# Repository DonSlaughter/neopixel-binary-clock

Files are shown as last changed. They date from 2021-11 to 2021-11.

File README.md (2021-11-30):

# neopixel-binary-clock
Binary clock using Neopixels, ESP8266 and DS3231 real time clock.
I used PlatformIO for this Project. The Arduino IDE will do fine i guess.

# Known Problems
The first LED has some kind of Voltage spikes if WiFi is enabled. The trick is
to Compile this Code that the RTC gets a Timestamp and then Compile this Code
without WiFi. If someone can help with that it would be great, but it works
without WiFi.

# PCB Design
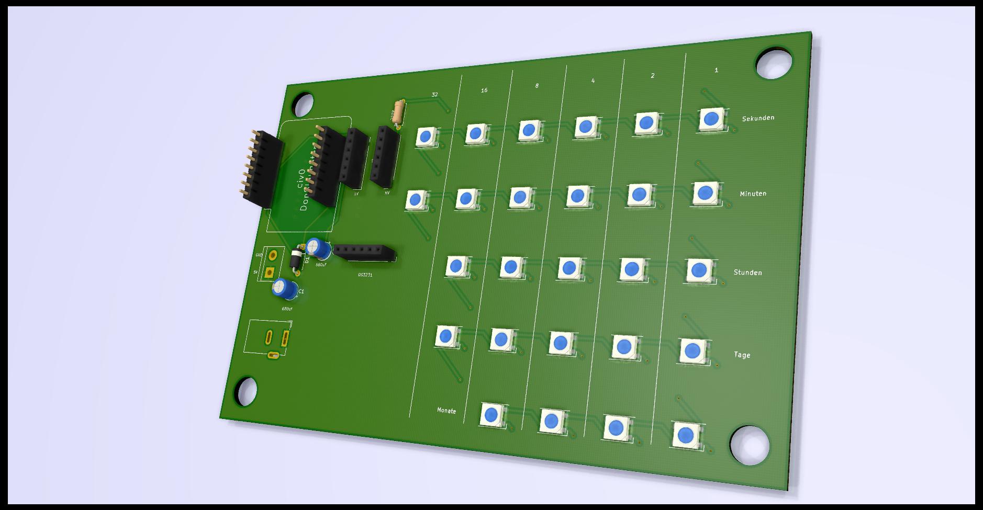
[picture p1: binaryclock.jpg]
pcb


# idea from civ0
https://github.com/civ0/neopixel-binary-clock

## Timezones
Timeszones are changend with Lib 'Timezones.h'
Everything can be changed with TimeChangeRule.

## Parts
* ESP8266 WeemosD1 Mini
* Logic Level Shifter
* DS3231
* 220 Ohm Resistor
* Schottky Diode with low Voltage drop
* 2 x Capacitor 680uF
* Barrel Jack
* Screw Terminal
* 26 x WS2812B SMD Led's

## Connect to Wi-Fi
create a file named secrets.h in the folder src.
it should contain your wifi network (ssid) and your wifi password:
```c
const char *ssid = "";
const char *pass = "";
```
## Code
Code needs to be cleand up

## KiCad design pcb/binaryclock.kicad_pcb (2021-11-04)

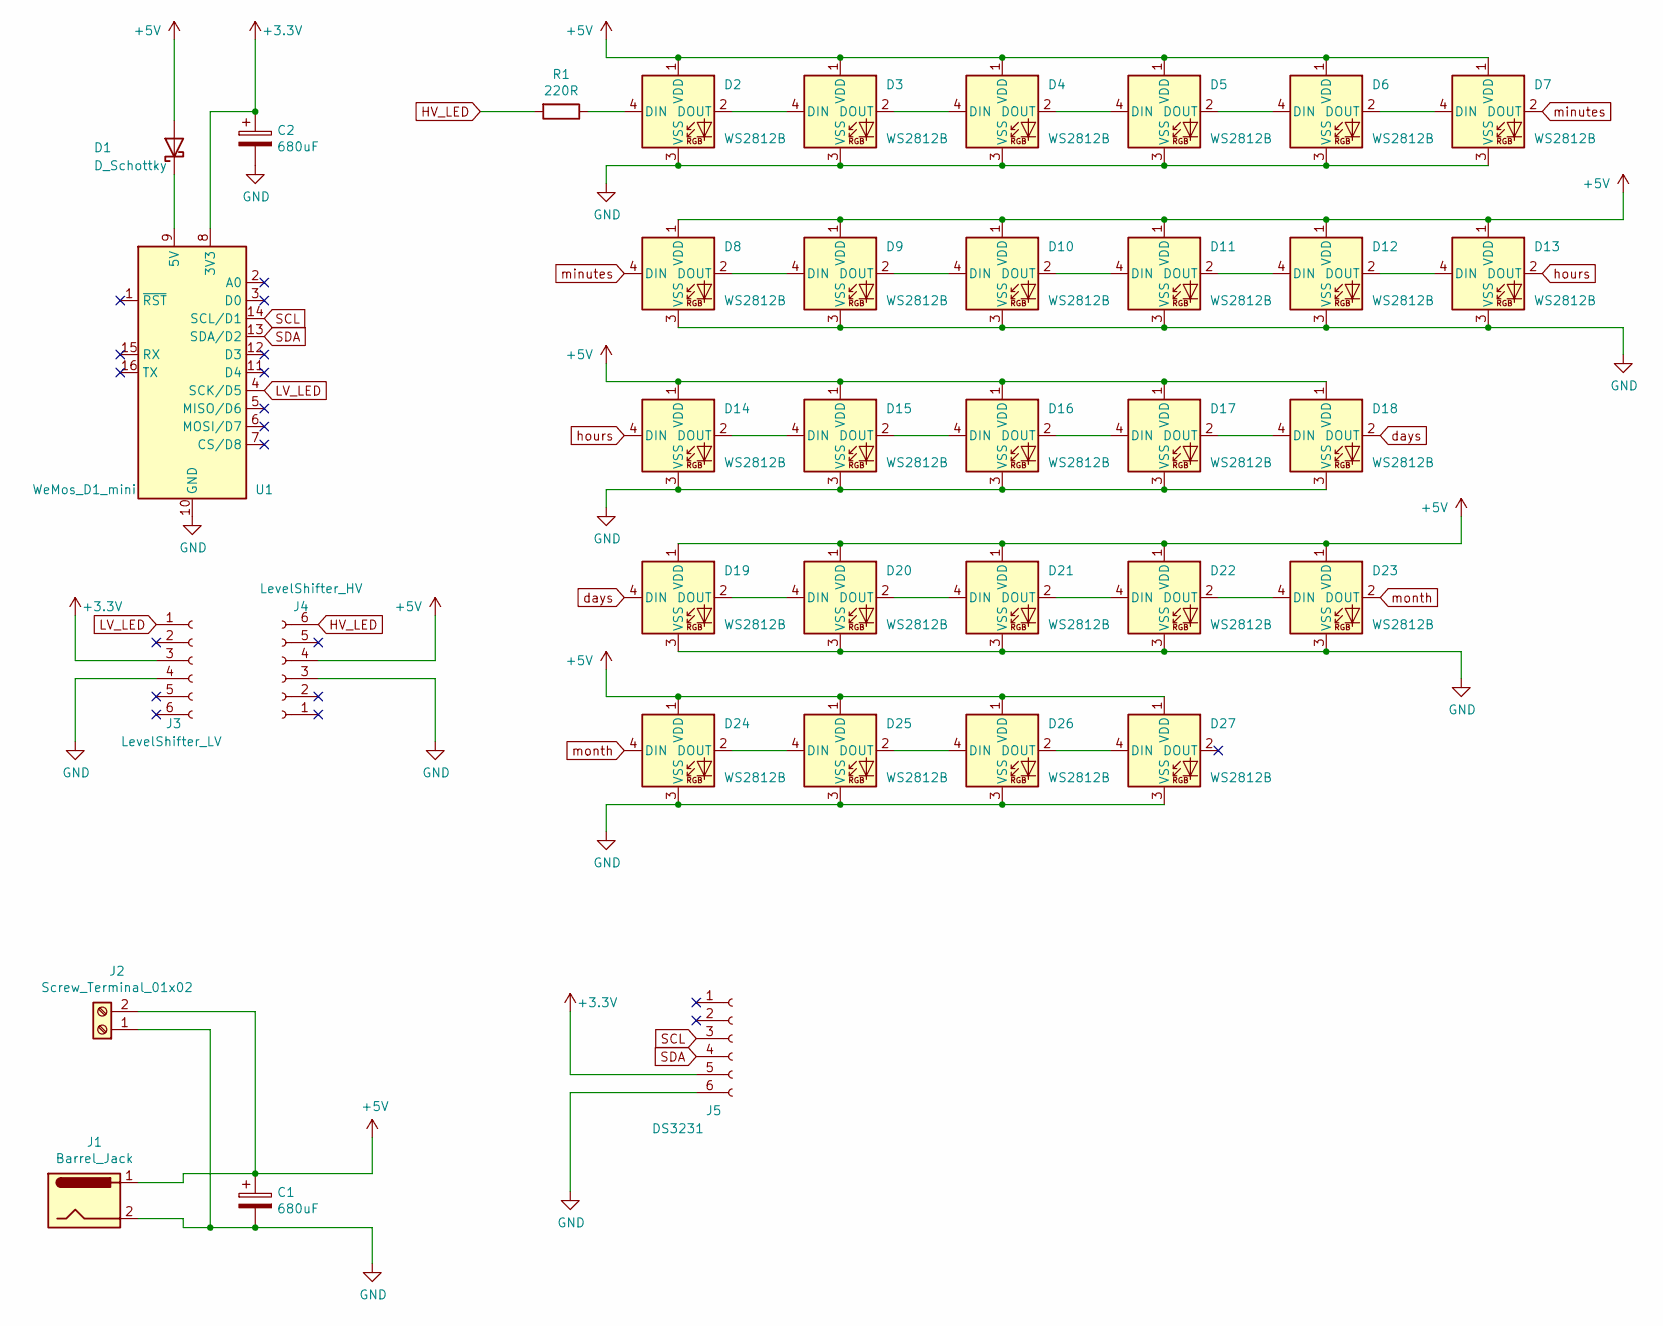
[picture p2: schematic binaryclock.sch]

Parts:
C1, C2: 680uF; CP_Radial_D5.0mm_P2.50mm
D1: D_Schottky; D_A-405_P7.62mm_Horizontal
D2, D3, D4, D5, D6, D7, D8, D9, D10, D11, D12, D13, D14, D15, D16, D17, D18, D19, D20, D21, D22, D23, D24, D25, D26, D27: WS2812B; LED_WS2812B_PLCC4_5.0x5.0mm_P3.2mm
J1: Barrel_Jack; BarrelJack_Wuerth_6941xx301002
J2: Screw_Terminal_01x02; TerminalBlock_bornier-2_P5.08mm
J3: LevelShifter_LV; PinSocket_1x06_P2.54mm_Vertical
J4: LevelShifter_HV; PinSocket_1x06_P2.54mm_Vertical
J5: DS3231; PinSocket_1x06_P2.54mm_Vertical
R1: 220R; R_Axial_DIN0207_L6.3mm_D2.5mm_P7.62mm_Horizontal
U1: WeMos_D1_mini; WEMOS_D1_mini_light

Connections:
+3V3: C2.1, J3.3, J5.5, U1.8 (3V3)
+5V: C1.1, D1.2 (A), D2.1 (VDD), D3.1 (VDD), D4.1 (VDD), D5.1 (VDD), D6.1 (VDD), D7.1 (VDD), D8.1 (VDD), D9.1 (VDD), D10.1 (VDD), D11.1 (VDD), D12.1 (VDD), D13.1 (VDD), D14.1 (VDD), D15.1 (VDD), D16.1 (VDD), D17.1 (VDD), D18.1 (VDD), D19.1 (VDD), D20.1 (VDD), D21.1 (VDD), D22.1 (VDD), D23.1 (VDD), D24.1 (VDD), D25.1 (VDD), D26.1 (VDD), D27.1 (VDD), J1.1, J2.2, J4.4
GND: C1.2, C2.2, D2.3 (VSS), D3.3 (VSS), D4.3 (VSS), D5.3 (VSS), D6.3 (VSS), D7.3 (VSS), D8.3 (VSS), D9.3 (VSS), D10.3 (VSS), D11.3 (VSS), D12.3 (VSS), D13.3 (VSS), D14.3 (VSS), D15.3 (VSS), D16.3 (VSS), D17.3 (VSS), D18.3 (VSS), D19.3 (VSS), D20.3 (VSS), D21.3 (VSS), D22.3 (VSS), D23.3 (VSS), D24.3 (VSS), D25.3 (VSS), D26.3 (VSS), D27.3 (VSS), J1.2, J2.1, J3.4, J4.3, J5.6, U1.10 (GND)
HV_LED: J4.6, R1.2
LV_LED: J3.1, U1.4 (SCK/D5)
unnamed: D1.1 (K), U1.9 (5V)
unnamed: D2.2 (DOUT), D3.4 (DIN)
unnamed: D2.4 (DIN), R1.1
unnamed: D3.2 (DOUT), D4.4 (DIN)
unnamed: D4.2 (DOUT), D5.4 (DIN)
unnamed: D5.2 (DOUT), D6.4 (DIN)
unnamed: D6.2 (DOUT), D7.4 (DIN)
unnamed: D8.2 (DOUT), D9.4 (DIN)
unnamed: D10.2 (DOUT), D11.4 (DIN)
unnamed: D9.2 (DOUT), D10.4 (DIN)
unnamed: D11.2 (DOUT), D12.4 (DIN)
unnamed: D12.2 (DOUT), D13.4 (DIN)
unnamed: D14.2 (DOUT), D15.4 (DIN)
unnamed: D15.2 (DOUT), D16.4 (DIN)
unnamed: D16.2 (DOUT), D17.4 (DIN)
unnamed: D17.2 (DOUT), D18.4 (DIN)
unnamed: D19.2 (DOUT), D20.4 (DIN)
unnamed: D20.2 (DOUT), D21.4 (DIN)
unnamed: D21.2 (DOUT), D22.4 (DIN)
unnamed: D22.2 (DOUT), D23.4 (DIN)
unnamed: D24.2 (DOUT), D25.4 (DIN)
unnamed: D25.2 (DOUT), D26.4 (DIN)
unnamed: D26.2 (DOUT), D27.4 (DIN)
SCL: J5.3, U1.14 (SCL/D1)
SDA: J5.4, U1.13 (SDA/D2)
days: D18.2 (DOUT), D19.4 (DIN)
hours: D13.2 (DOUT), D14.4 (DIN)
minutes: D7.2 (DOUT), D8.4 (DIN)
month: D23.2 (DOUT), D24.4 (DIN)

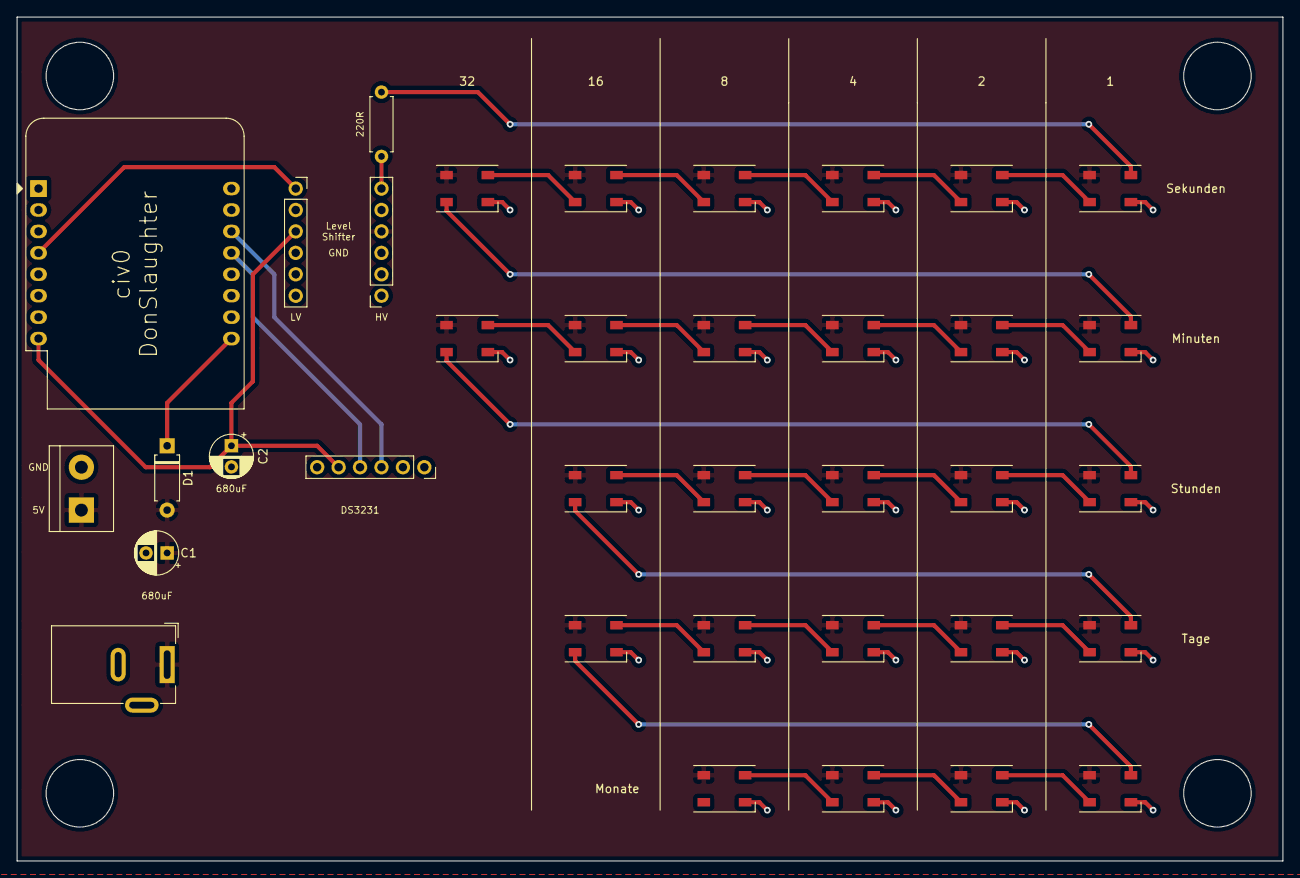
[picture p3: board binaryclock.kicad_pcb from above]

Board: 2 copper layers, 150.0 x 100.0 mm, 36 parts (0 on the bottom side), 34 nets.

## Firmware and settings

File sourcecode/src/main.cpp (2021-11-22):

#include <Arduino.h>
#include <Wire.h>
#include <RtcDS3231.h>
#include <TimeLib.h>
#include <Timezone.h>
//#define FASTLED_ALLOW_INTERRUPTS 0
//#define INTERRUPT_THRESHOLD 1
//#define FASTLED_INTERRUPT_RETRY_COUNT 0
#include <FastLED.h>
#include "secrets.h"
#include "main.h"
//Turning WiFi off or on. It seems there are som interrupt Bugs concerning the
//WiFi. If Wifi is turned off the Clock will work as expected. If it is turned
//on the first LED will flicker.
#define WITH_WLAN 0
#if WITH_WLAN
#include <ESP8266WiFi.h>
#include <WiFiUdp.h>
#include <NTPClient.h>

// Define NTP Client to get time
WiFiUDP ntpUDP;
//NTPClient updates normall every minute
NTPClient timeClient(ntpUDP, "europe.pool.ntp.org");
#endif

//Changing Timezone and using Daylightsaving
TimeChangeRule mySTD = {"CET", Last, Sun, Oct, 3, 60};
TimeChangeRule myDST = {"CEST", Last, Sun, Mar, 2, 120};
Timezone myTZ(myDST, mySTD);
TimeChangeRule *tcr;

RtcDS3231<TwoWire> Rtc(Wire);
//SCL pin D1
//SDA pin D2

//time_t sctructs to store timevalues
time_t utc;
time_t local;
time_t old_local;
time_t night_time;

//LED Parameter and definitions
#define LED_PIN D5
#define NUM_LEDS 26
#define COLOR_ORDER BRG

const uint8_t saturation = 255;
uint8_t value = 20;
//Night Mode parameters:
uint8_t high_brightness = 100;
uint8_t dimmed_brightness = 20;
uint8_t start_hour = 20;
uint8_t stop_hour = 7;

CHSV Colors[5];
CHSV Black(0,0,0);

CRGB leds[NUM_LEDS];

bool night_mode = true;


void setup()
{
	Serial.begin(115200);
	delay(250);
	FastLED.addLeds<WS2812B, LED_PIN, COLOR_ORDER>(leds, NUM_LEDS);
	//test_all_leds();
	Colors[0] = CHSV(0, saturation, value);
	Colors[1] = CHSV(51, saturation, value);
	Colors[2] = CHSV(102, saturation, value);
	Colors[3] = CHSV(153, saturation, value);
	Colors[4] = CHSV(204, saturation, value);

	Rtc.Begin();
#if WITH_WLAN
	connect_to_wifi();
	print_connection();
	timeClient.begin();
	RTC_Update();
#endif
	utc = Rtc.GetDateTime();
	old_local = myTZ.toLocal(utc, &tcr);
	//old_local = time(NULL);
	delay(10);
}

void loop()
{
	utc =  Rtc.GetDateTime();
	local = myTZ.toLocal(utc, &tcr);
	if (second(local) != second(old_local)){
		printDateTime(local, tcr -> abbrev);
		night_mode_on();
		WS2812B_Write_Time();
		old_local = myTZ.toLocal(utc, &tcr);
		change_colors();
		//delay(10);
	}
}

#if WITH_WLAN
void connect_to_wifi()
{
	Serial.print("Connecting to ");
	Serial.println(ssid);
	WiFi.begin(ssid, pass);
	while (WiFi.status() != WL_CONNECTED) {
		delay(500);
		Serial.print(".");
	}
}

void print_connection()
{
	Serial.println();
	Serial.print("Connected to: ");
	Serial.println(ssid);
	Serial.print("Local IP-Adress: ");
	Serial.println(WiFi.localIP());
}

void RTC_Update()
{
	timeClient.update();
	unsigned long epochTime = timeClient.getEpochTime();
	Rtc.SetDateTime(epochTime);
	Serial.println("Time Set");
	timeClient.end();
}
#endif

void change_colors()
{
	uint8_t gHueDelta = 1;
	for (uint8_t i = 0; i < 5; i++) {
		Colors[i].hue += gHueDelta;
		Colors[i].val = value;
	}
}

void printDateTime(time_t t, const char *tz)
{
	char buf[32];
	char m[4];    // temporary storage for month string (DateStrings.cpp uses shared buffer)
	strcpy(m, monthShortStr(month(t)));
	sprintf(buf, "%.2d:%.2d:%.2d %s %.2d %s %d %s",
		hour(t), minute(t), second(t), dayShortStr(weekday(t)), day(t), m, year(t), tz);
	Serial.println(buf);
}

void WS2812B_Write_Time()
{
	WS2812B_Write_Number(0, 5, second(local), Colors[0]);
	WS2812B_Write_Number(6, 11, minute(local), Colors[2]);
	WS2812B_Write_Number(12, 16, hour(local), Colors[4]);
	WS2812B_Write_Number(17, 21, day(local), Colors[1]);
	WS2812B_Write_Number(22, 25, month(local), Colors[3]);
	FastLED.show();
}

void WS2812B_Write_Number(uint8_t startIndex, uint8_t endIndex, uint8_t number, CHSV color)
{
	uint8_t mask = 1;
	for (uint8_t i = startIndex ; i <= endIndex ; i++) {
		if ((number & mask) != 0) {
			leds[i] = color;
		}
		else {
			leds[i] = Black;
		}
		mask = mask << 1;
	}
}

void night_mode_on()
{
	if (night_mode == true) {
		if ((hour(local) >= start_hour) || ((hour(local) >= 0) && (hour(local) <= stop_hour))) {
			value = dimmed_brightness;
		}
		else {
			value = high_brightness;
		}
	}
}

//Debug Functions

void test_all_leds()
{
	char buf[20];
	Serial.print("Starting Test");
	for (uint8_t i = 0; i <= NUM_LEDS; i++){
		leds[i] = CRGB::Red;
		FastLED.show();
		sprintf(buf, "Led %d, Color Red", i);
		Serial.println(buf);
		delay(100);
		leds[i] = CRGB::Green;
		FastLED.show();
		sprintf(buf, "Led %d, Color Green", i);
		Serial.println(buf);
		delay(100);
		leds[i] = CRGB::Blue;
		FastLED.show();
		sprintf(buf, "Led %d, Color Blue", i);
		Serial.println(buf);
		delay(100);
		leds[i] = CRGB::Black;
		FastLED.show();
		sprintf(buf, "Led %d, off", i);
		Serial.println(buf);
	}
}

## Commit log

2021-10-10 dont track compile commands
2021-10-10 dont track compile commands_1
2021-10-30 pcb finished
    [binaryclock.kicad_pcb, binaryclock.sch]
2021-11-08 still fuckup with 1st led
2021-11-08 working without wifi but led_s allright
